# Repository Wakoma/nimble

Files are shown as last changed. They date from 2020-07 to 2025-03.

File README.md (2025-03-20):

<!--
SPDX-FileCopyrightText: 2020-2023 Eric Nitschke <eric@wakoma.co>
SPDX-FileCopyrightText: 2023 Robin Vobruba <hoijui.quaero@gmail.com>

SPDX-License-Identifier: CERN-OHL-S-2.0
-->

# nimble

[](
    https://spdx.org/licenses/CERN-OHL-S-2.0.html)
[](
    https://api.reuse.software/info/github.com/Wakoma/nimble)

<p align="center">nimble logo 256</p>

An open source, rapidly deployable, wireless mesh network. 

Anyone connected to the nimble can video and voice chat, stream videos, share files, build and run eLearning courses and website, create collaborative spreadsheets and documents, read e-books, play games, and so much more… completely offline. 

If a single internet connection is available, it can be plugged into the nimble to provide free or paid internet access to anyone on the network. The offline services and content are always available to users, regardless of internet availability.

Anyone in the world can build their own nimble with locally sourced hardware and 3D-printed components.

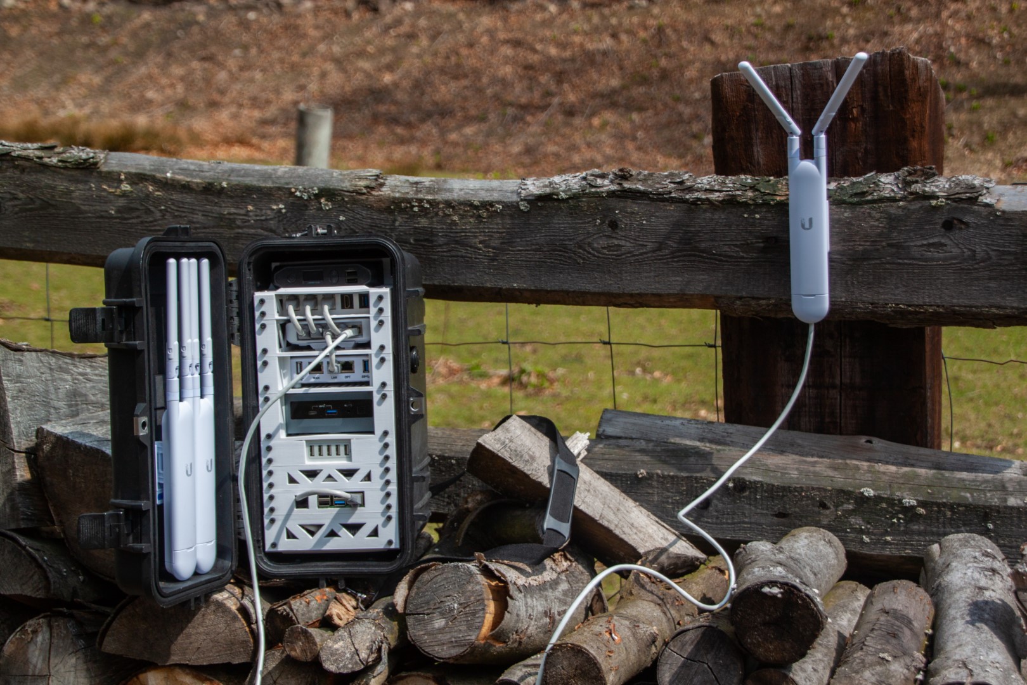
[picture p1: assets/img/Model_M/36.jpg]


## State of this repository

In 2024 we received a grant from NLnet Foundation to develop a smart documentation system which automatically generates all documentation and 3D models needed for any custom nimble configuration. 

<p align="center">6in NUC shelf</p>

See the announcement [here](https://nlnet.nl/project/HardwareManuals/).
Have a look at the other incredible projects they support [here](https://nlnet.nl/project/0).

A sneek preview of the nimble builder:

<p align="center">6in NUC shelf</p>

To create our interactive documentation generator we ended up creating an entirely new library called [CadOrchestrator](https://gitlab.com/gitbuilding/cadorchestrator).

## Useful Links

* [Nimble website](https://wakoma.co/nimble/)
* [Nimble printables page](https://www.printables.com/model/80708-wakoma-nimble-new-2021-model)
* [GitBuilding Repo](https://gitlab.com/gitbuilding/)
* Project Blogpost 1: [OTFN Hackathon](https://7bindustries.com/blog/otfn_hackathon.html).
* Project Blogpost 2: [Project Initiation](https://7bindustries.com/blog/nimble_project_1.html/

## Support

For more info have a look at <https://wakoma.co/nimble>,
or reach out to <mailto:info@wakoma.co>.

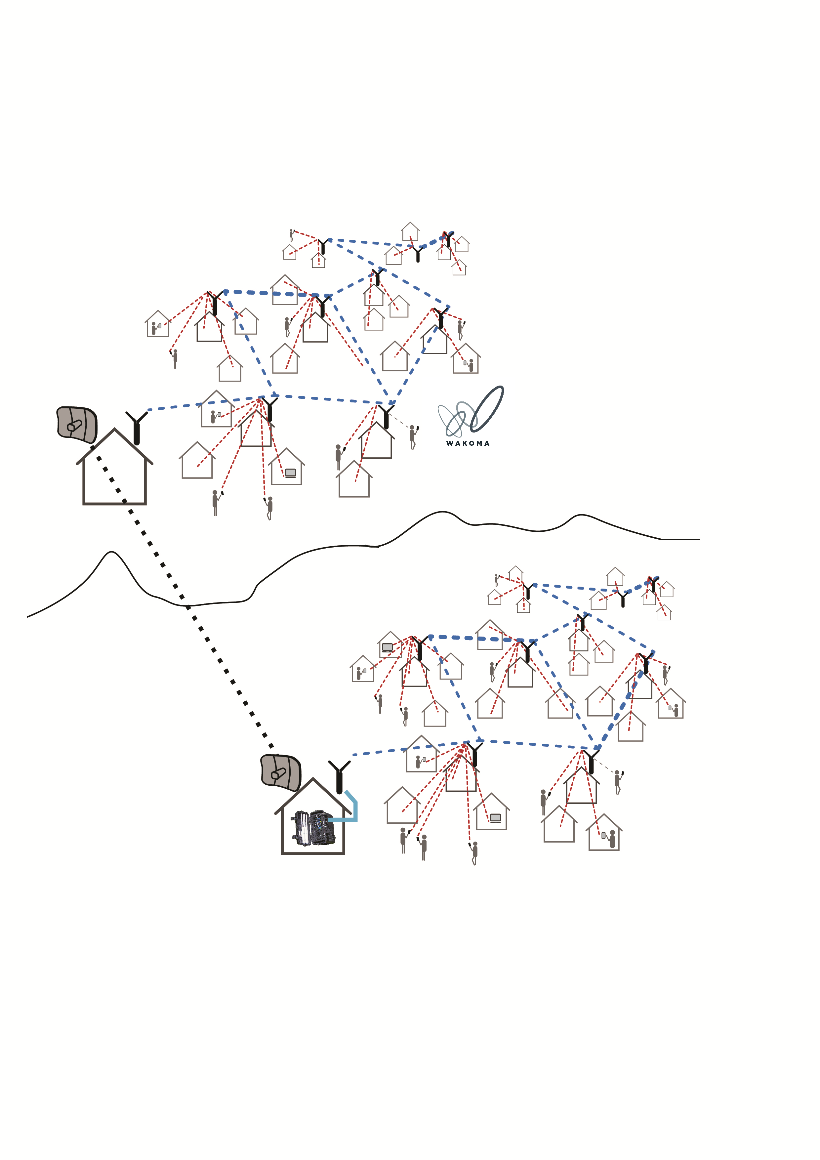
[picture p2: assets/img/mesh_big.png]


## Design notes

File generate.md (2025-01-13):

<!--
SPDX-FileCopyrightText: 2023 Andreas Kahler <mail@andreaskahler.com>

SPDX-License-Identifier: CERN-OHL-S-2.0
-->

# Automatic generation of configured Nimble hardware

## Overview

Nimble hardware models are generated using Python. For CAD we used [CadQuery](https://cadquery.readthedocs.io/en/latest/intro.html). CadQuery scripts can be found in the `mechanical` directory, with individual components in the `mechanical/components/cadquery` directory. Our CadQuery scripts also use the `nimble-builder` module of helper functions.

Our preferred way to generate the models needed for a nimble configuration is via our orchestration module `nimble-orchestration`. This uses an orchestration tool called [CadOrchestrator](https://gitlab.com/gitbuilding/cadorchestrator) This can be used to generate trays for networking components, nimble-rack components, and a final CAD assembly. The orchestration system uses [cq-cli](https://github.com/CadQuery/cq-cli) to execute CadQuery scripts, and [ExSource Tools](https://gitlab.com/gitbuilding/exsource-tools) to manage the process of turning scripts into useable models. The orchestration script will eventually use [GitBuilding](https://gitbuilding.io) to generate assembly manuals.

## Installation

You must have [Python 3.10](https://www.python.org/about/gettingstarted/) or higher installed on your system and also have pip installed. We recommend that you use a [Python virtual environment](https://realpython.com/python-virtual-environments-a-primer/) for interacting with nimble.

Clone or download this repository to your computer

Open a terminal (for example PowerShell in Windows) and navigate to this repository

Run:

    pip install -e .

*Note, if pip doesn't work depending on your system is configured you man need to replace `pip` with `pipx`, `pip3`, or `python -m pip`.*

## Running the code

### Lunching the configuration server

Starting in the root directory of this project. First you will need to generate the configuration options. To do this run:

    gen_nimble_conf_options

Next run:

    cadorchestrator serve

The server should now be available at http://127.0.0.1:8000/

### Generating a specific configuration from command line

The script `cadorchestrator generate` can be used generating a complete set of information for a nimble configuration from the command line.

Currently the configuration is just a list of the networking components which are hard coded. At a future date it should be possible to pass a configuration and other parameters to this script.

To generate run the following:

    cadorchestrator generate '{"device-ids": ["NUC10i5FNH", "Raspberry_Pi_4B", "Raspberry_Pi_4B"]}'

This should create the `build` directory. Inside this the `printed_components` directory should contain a number of `stl` files that can be 3D printed. It will also contain `step` files for each of these components.

The script also creates an `stl` and a `gltf` of the final assembled rack. **Don't print this, it is not going to print properly as a single piece!**

It also creates a number of files that are used by the orchestration script.

At a later date this script will be improved to create a directory (and associated zip-file of each configuration).

### Generate static

The script `generate-static.py` is used to create a number of example components for a Nimble rack. The script is not trying to support any specific configuration, but is instead being developed to provide a static library interface for which a large number of Nimble components can be downloaded.

To run this script, run the following command:

    python generate_static.py

This should create the `build` directory. Inside this the `printed_components` directory should contain a number of `stl` files that can be 3D printed.

The script also creates a simple web-page with an index of all of the files. The final link to the "Partially complete automatically generated documentation" will be broken unless you also run `generate.py` (see below).

It also creates a number of files that are used by the orchestration script.

If you don't want to run this locally you can see a [hosted version of the output](https://wakoma.github.io/nimble/).

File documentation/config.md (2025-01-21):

#  Your Nimble Configuration

The nimble is a modular rack-and-shelf system. The first part of construction is to 3D print the custom parts, and then to assemble the shelves.

The shelves in your system are:

{{listpages, tag:shelf}}

Once you have assembled each shelf, you will [construct the rack](construction.md){step}.

Make sure you have [all the parts you need]{bom}, before you start assembly.

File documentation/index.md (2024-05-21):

# Nimble Assembly Guide

## What is Nimble

Nimble is an open source, rapidly deployable, wireless mesh network.

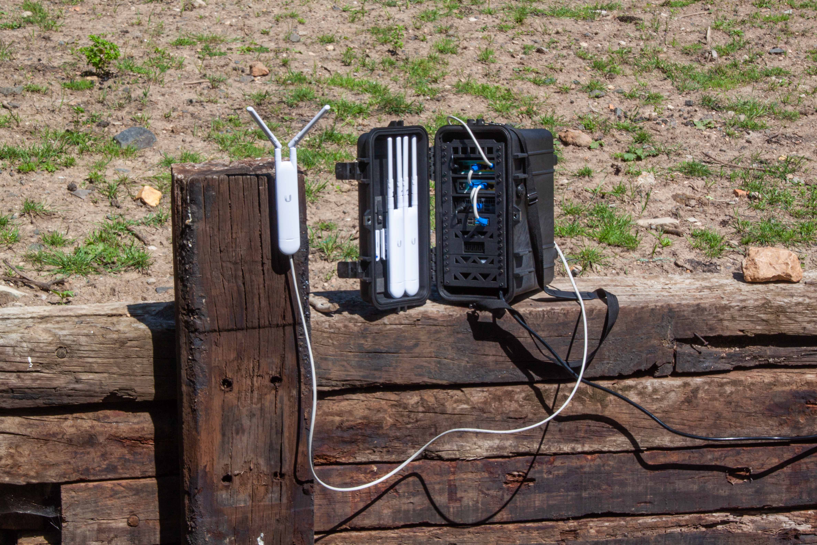
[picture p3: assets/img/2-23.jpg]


Anyone connected to the nimble can video and voice chat, stream videos, share files, build and run eLearning courses and websites, create collaborative spreadsheets and documents, read e-books, play games, and so much more… completely offline.

If a single internet connection is available, it can be plugged into the nimble to provide free or paid internet access to anyone on the network. The offline services and content are always available to users, regardless of internet availability.

Anyone in the world can build their own nimble with locally sourced hardware and 3D-printed components.

You can find out more about Nimble on [our website](https://wakoma.co/nimble/).

## Customisation

Nimble, as an open source project, is designed so that you can tailor it to your own needs and to the hardware that you have available.

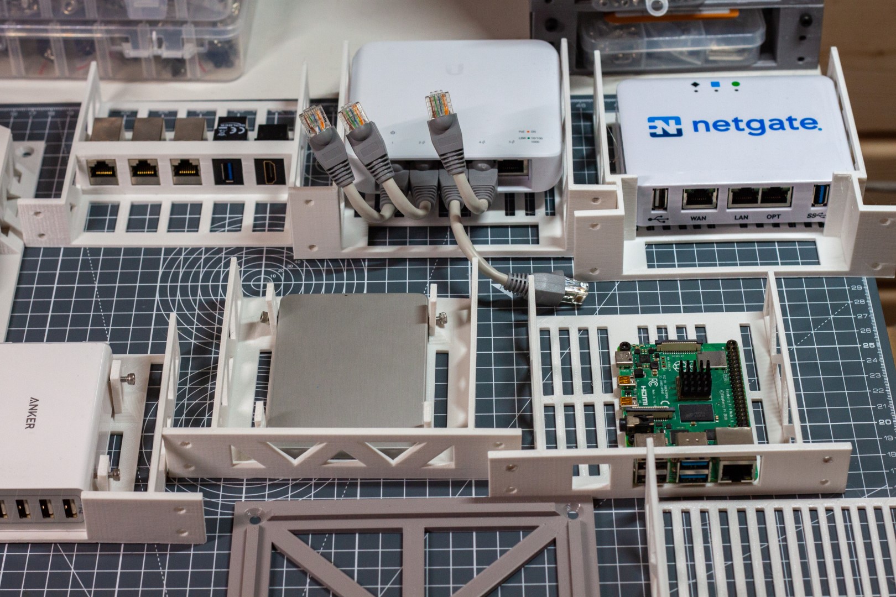
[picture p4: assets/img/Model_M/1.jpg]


We are [working on building an interface for customising your nimble](https://github.com/Wakoma/nimble/pull/23). In the mean time this is an example of the assembly instructions for a specific configuration.

To customise your Nimble you can go to [our GitHub](https://github.com/Wakoma/nimble). If you aren't sure where to start, you can always ask for help by [opening an issue](https://github.com/Wakoma/nimble/issues) or [starting a discussion](https://github.com/Wakoma/nimble/discussions).

## Building your Nimble

In the next pages we will build [your nimble](config.md){step}.

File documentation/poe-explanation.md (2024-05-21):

---
Tags: info
---

# Power over Ethernet (PoE)

Many of the devices in your Nimble are powered directly through the Ethernet cable.

Power over Ethernet allows both data and power to be transmitted between devices using only a single cable. This really cuts down on excess cables.

There is far more information on Power over Ethernet at [wikipedia](https://en.wikipedia.org/wiki/Power_over_Ethernet)

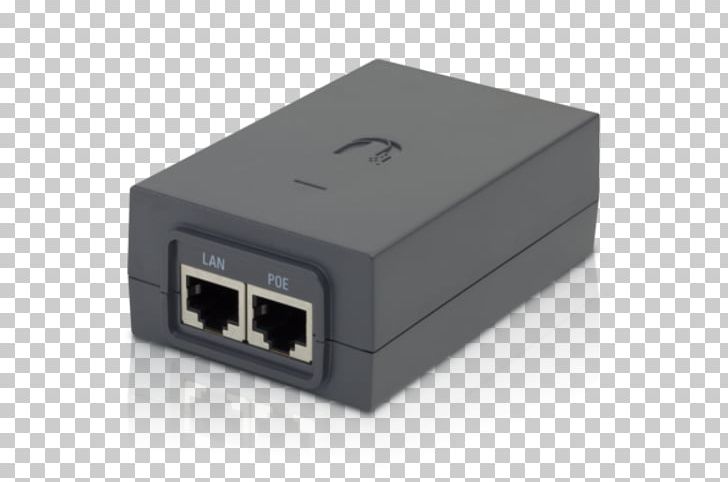
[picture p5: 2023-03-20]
assets/img/Network_Hardware/poe50.jpg

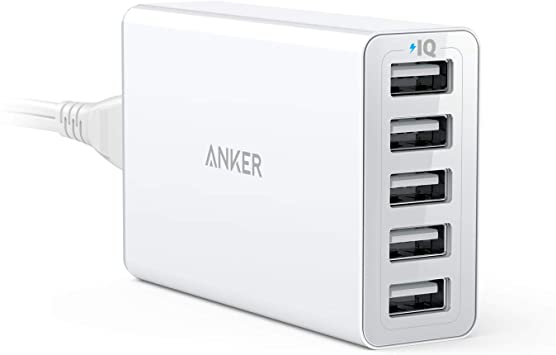
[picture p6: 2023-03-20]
assets/img/Network_Hardware/power2.jpg

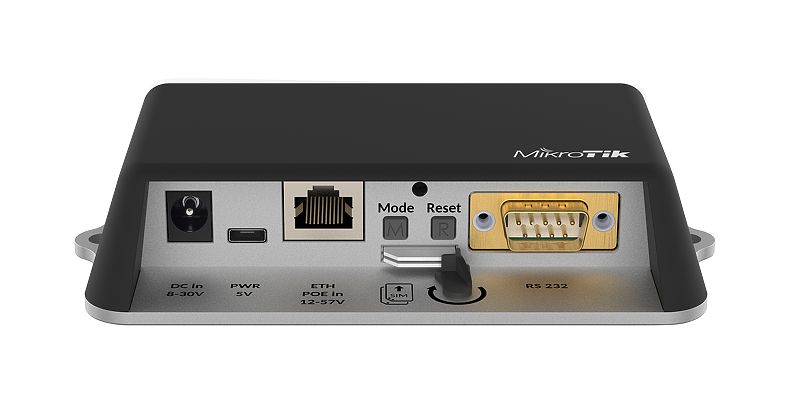
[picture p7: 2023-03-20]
assets/img/Network_Hardware/1604_l.jpg

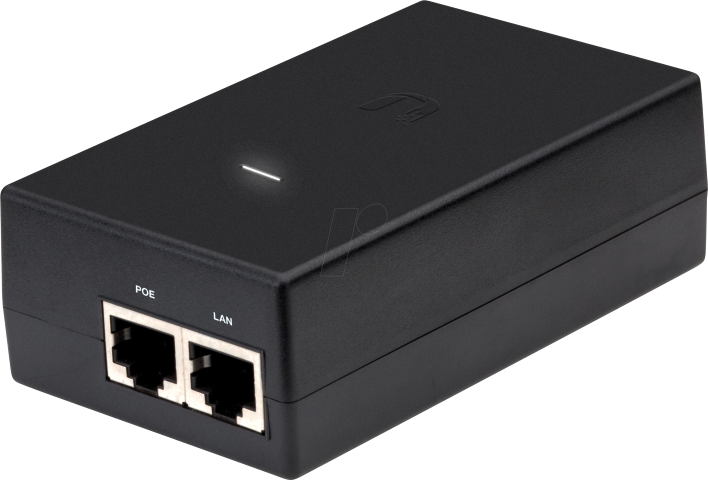
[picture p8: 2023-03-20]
assets/img/Network_Hardware/UBI_POE-50-60W_01_Small.png

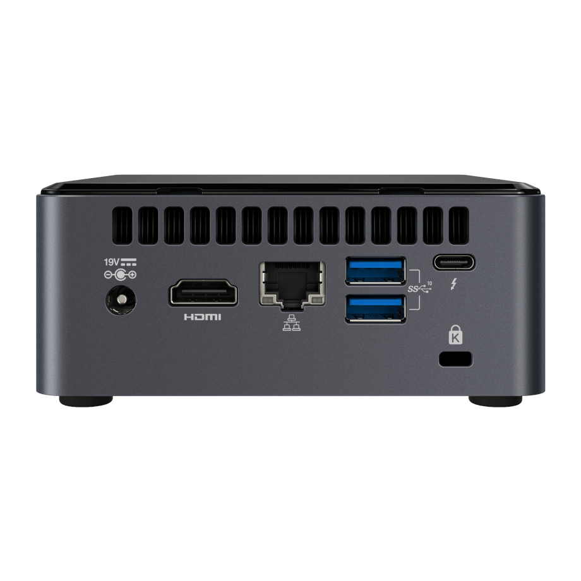
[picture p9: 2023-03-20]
assets/img/Network_Hardware/NUC10i5FNH.png

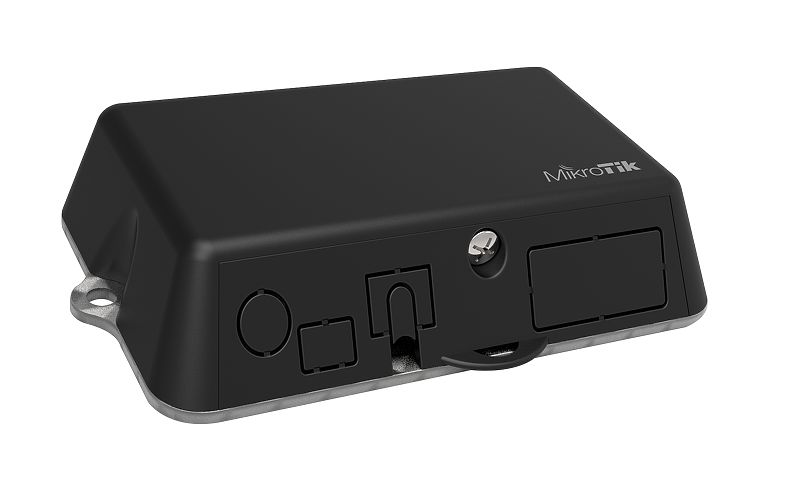
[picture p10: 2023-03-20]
assets/img/Network_Hardware/1513_l.jpg

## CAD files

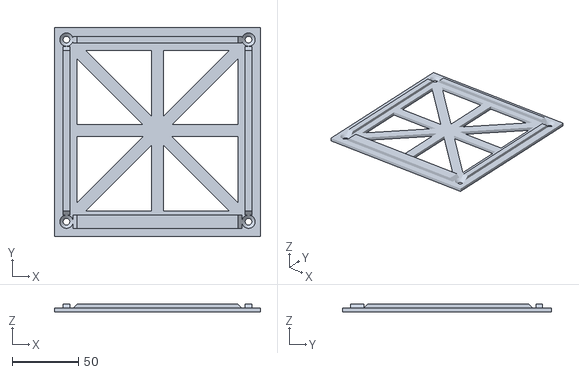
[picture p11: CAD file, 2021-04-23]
3D Designs/top-draft-v2.1-3mm.stl
155.0 x 157.0 x 6.00

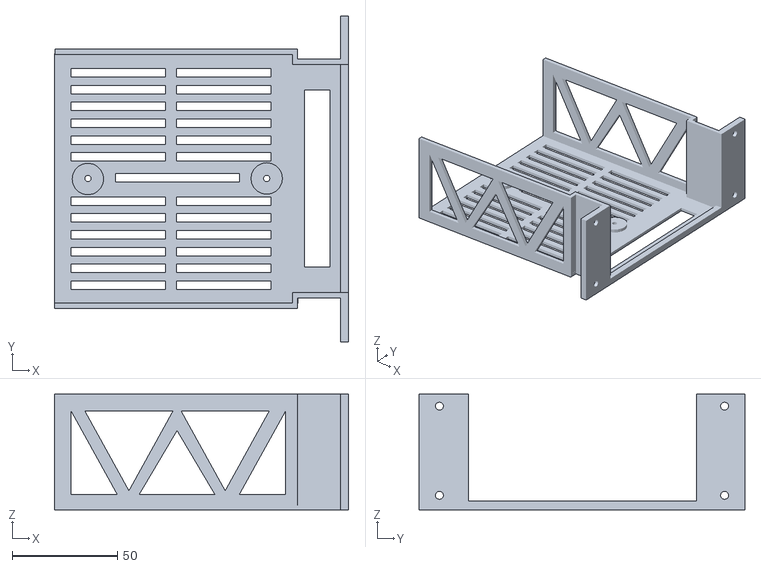
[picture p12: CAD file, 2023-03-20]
gen/mech/tall_nuc_shelf.stl
140.0 x 155.0 x 55.0

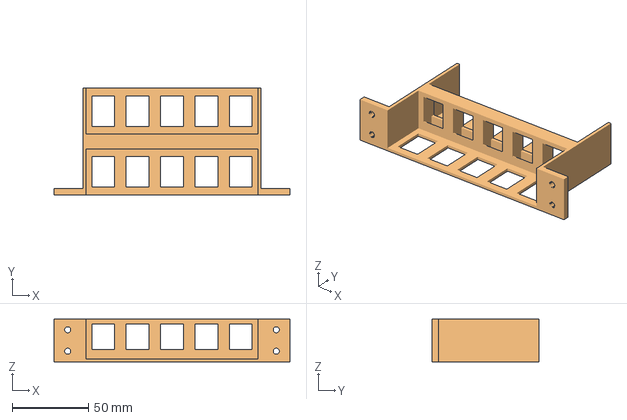
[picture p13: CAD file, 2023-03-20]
mechanical/components/FreeCAD/patch-panel.FCStd
155.0 x 70.0 x 28.0 mm
Fusion (Meshed)002

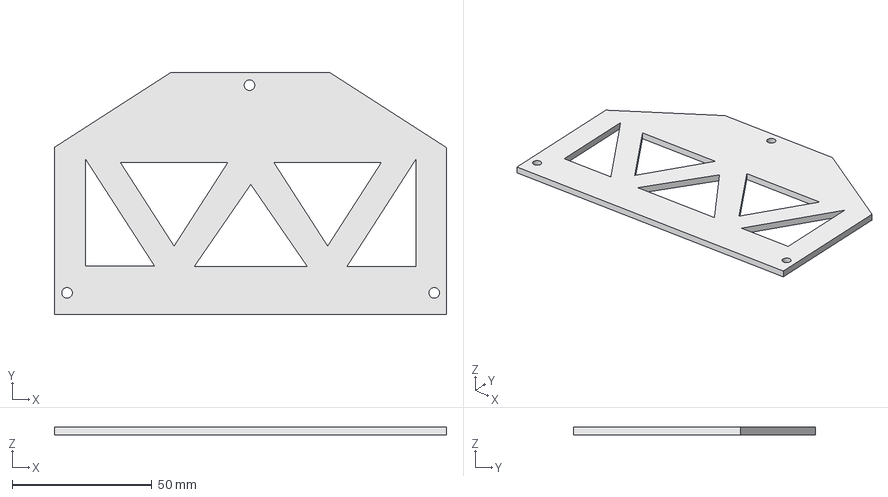
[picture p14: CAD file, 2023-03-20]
src/mech/freecad/omni_20_top.FCStd
140.5 x 86.9 x 2.80 mm

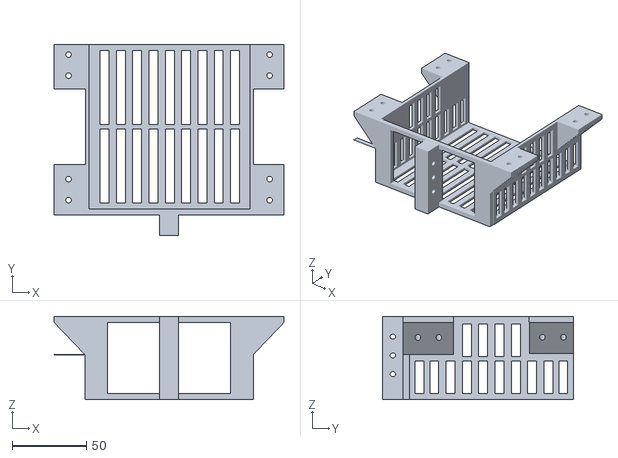
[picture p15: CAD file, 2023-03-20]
gen/mech/power_box.stl
155.1 x 129.0 x 56.0

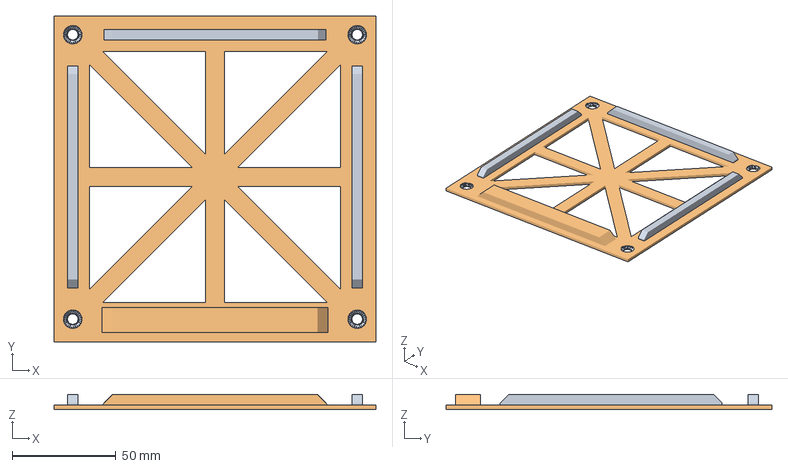
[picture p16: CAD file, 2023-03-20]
mechanical/components/FreeCAD/case-top-draft.FCStd
155.0 x 157.0 x 7.00 mm
Pocket001 (Meshed)004

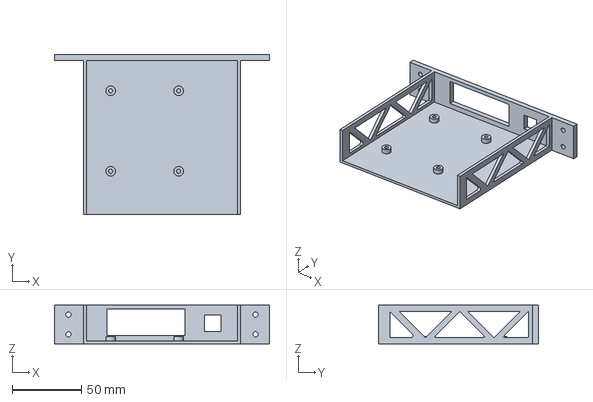
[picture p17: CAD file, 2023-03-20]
src/mech/freecad/rpi_4b_shelf.FCStd
155.0 x 115.0 x 28.0 mm

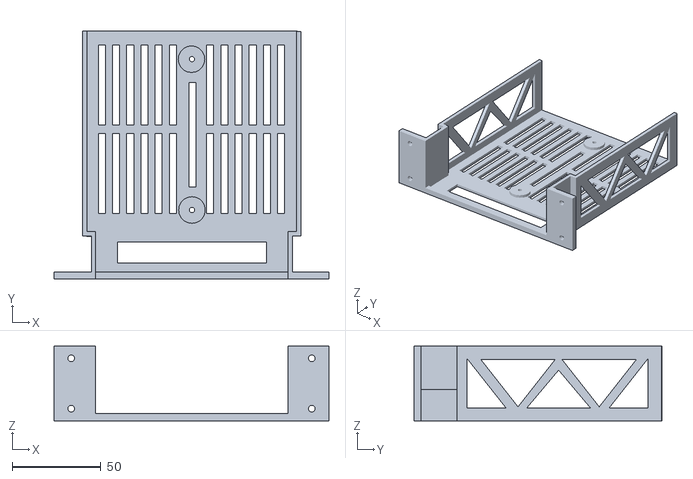
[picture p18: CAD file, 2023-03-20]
gen/mech/nuc_shelf2.stl
155.0 x 140.0 x 42.2

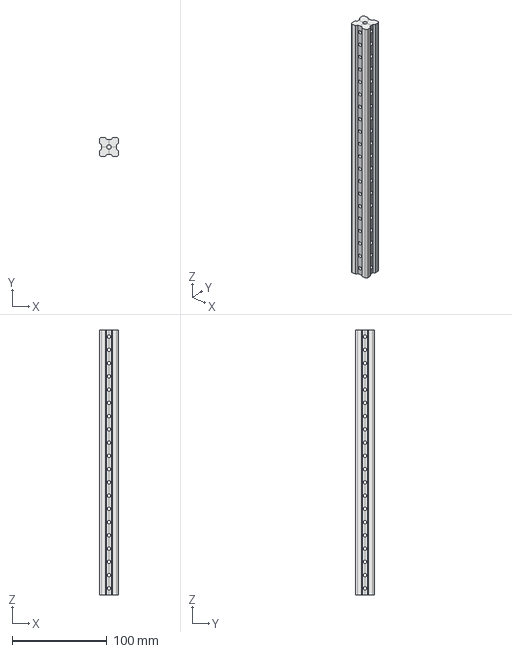
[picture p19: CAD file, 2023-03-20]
src/mech/freecad/master_rail.FCStd
20.0 x 20.0 x 280.0 mm

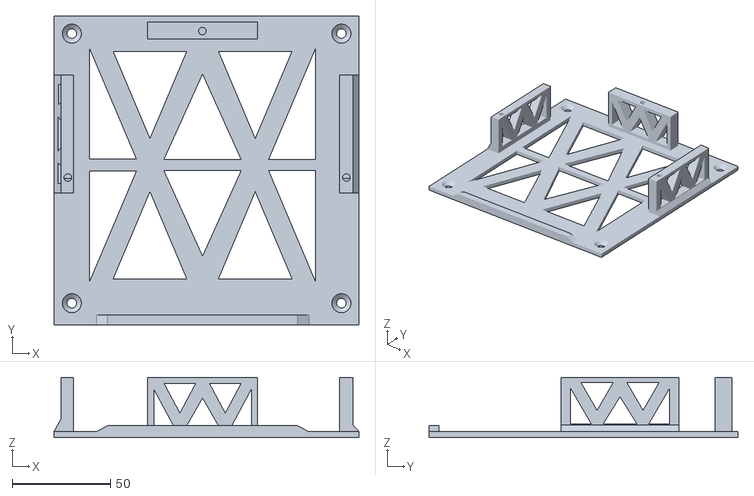
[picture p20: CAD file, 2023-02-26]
gen/mech/usg.stl
155.0 x 157.0 x 30.5

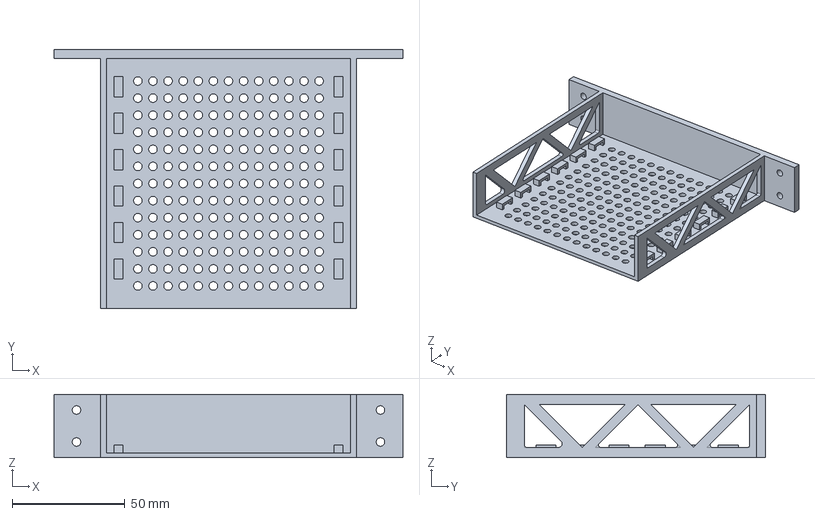
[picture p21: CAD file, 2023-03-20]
src/mech/freecad/base_shelf.FCStd
155.0 x 115.0 x 28.0 mm

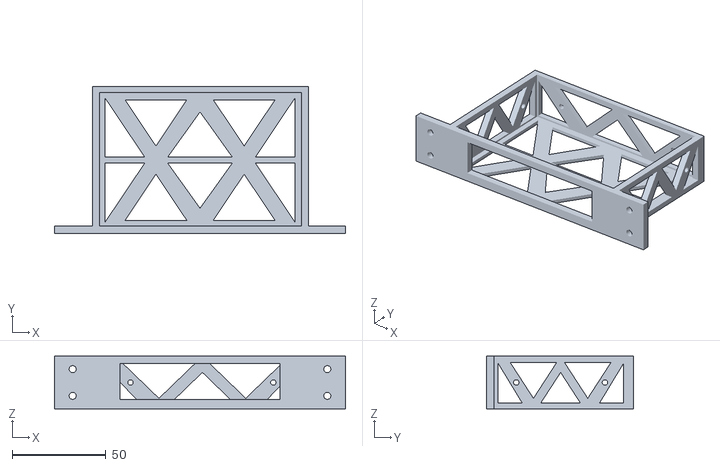
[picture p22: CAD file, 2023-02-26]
gen/mech/flex_mini_shelf.stl
155.0 x 78.1 x 28.0

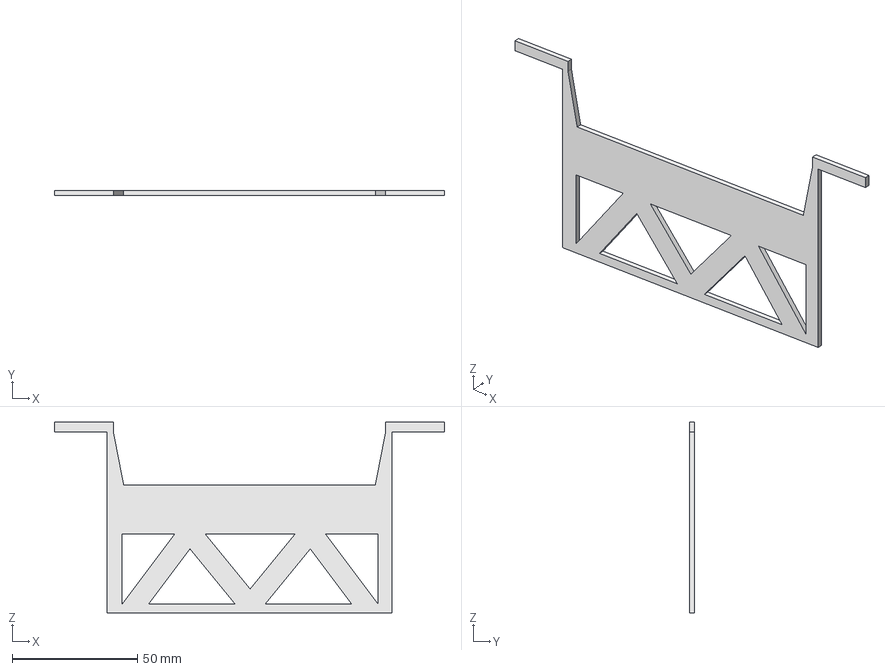
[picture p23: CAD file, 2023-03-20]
src/mech/freecad/triangle_master.FCStd
155.5 x 2.00 x 76.0 mm

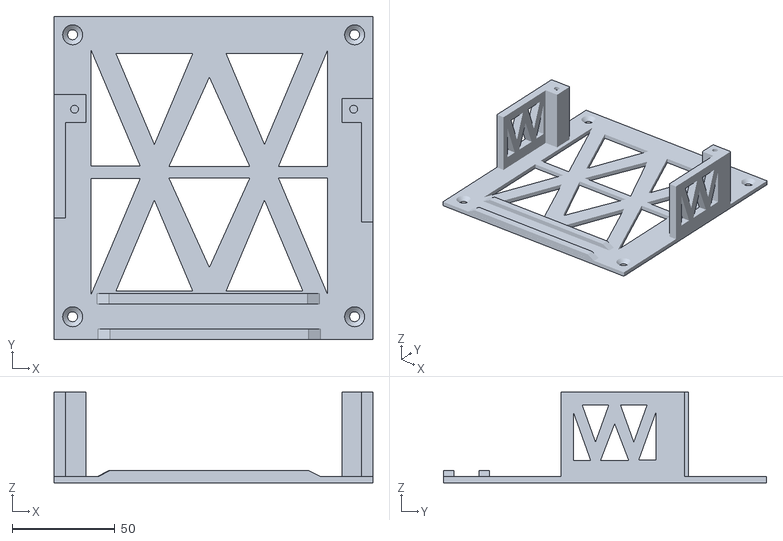
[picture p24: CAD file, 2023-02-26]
gen/mech/scarlett_solo.stl
155.0 x 157.0 x 44.0

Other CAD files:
gen/mech/ltap_mini_shallow.stl
gen/mech/keystone_patch_panel_2_units_short.stl
gen/mech/usg_top.stl
gen/mech/ap_mount_for_1430_top.stl
gen/mech/3.5_hdd_shelf.stl
gen/mech/ap_mount_for_1430.stl
gen/mech/ap_mount_for_1430_bottom.stl
gen/mech/dual_ssd_shelf.stl
gen/mech/generic_shelf.stl
gen/mech/keystone_patch_panel_2_units.stl
gen/mech/mikrotik_shelf.stl
gen/mech/nuc_shelf.stl
gen/mech/nuc_shelf_tall.stl
gen/mech/omni_20.stl
gen/mech/omni_20_top.stl
gen/mech/patch_panel_2_units.stl
gen/mech/power_cage.stl
gen/mech/rack_leg_21_units.stl
gen/mech/rpi_4b_shelf.stl
gen/mech/sg-1100_shelf.stl
gen/mech/stuff_shelf_thin.stl
gen/mech/top.stl
gen/mech/usb_hub_shelf.stl
gen/mech/usw-flex_shelf.stl
mechanical/Legacy/STLs/3.5_hdd_shelf.stl
mechanical/Legacy/STLs/ap_mount_for_1430.stl
mechanical/Legacy/STLs/ap_mount_for_1430_bottom.stl
mechanical/Legacy/STLs/ap_mount_for_1430_top.stl
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

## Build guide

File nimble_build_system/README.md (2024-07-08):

The nimble build system is a python module containing custom functionality for building the nimble hardware.

This is divided into three sub-packages:

* `cad` - This contains any helper functions for building the Nimble CAD models. This does not contain the scripts for generating specific CAD models and assemblies. These are held in the `mechanical` directory of the repository.
* `orchestration` - This contains code for the Nimble project's interaction with [CadOrchestrator](https://gitlab.com/gitbuilding/cadorchestrator)
* `utils` - This contains assorted utility scripts, for example for updating the JSON configuration files.

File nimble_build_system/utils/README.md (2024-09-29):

The utilities sub-module of the nimble build system contains scripts that are needed for project specific tasks such as updating config files

## nimble_devices_updater.py

This converts the CSV that is downloaded from NocoDB into something that can be used by the orchestration/generation scripts. The scripts use the `devices.json` file that is in the root of this repository. This should eventually be replaced by a direct connection via the NocoDB API. This utility requires that it be passed the path to the CSV file to convert.

**Usage:**

```bash
./nimble_devices_updater.py
```

The `devices.json` file it creates is committed to the repository.

## gen_nimble_conf_options.py

This script used `devices.json` to create the configuration used by CadOrchestrator to set the configuration options that the user can select when generating a nimble.

Assuming that the `nimble_build_system` is installed using setup.py, this script is as an entry point and should be on your PATH.

Starting in the root directory of this project, run:

```bash
gen_nimble_conf_options
```

This will generate the configuration options in the file `OrchestratorConfigOptions.json`. This file is ignored by Git.

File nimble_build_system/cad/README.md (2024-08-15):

This directory holds CAD files that are used to generate Nimble racks.

# Dimension Names

Standard dimension names are needed to ensure proper orientation of the shelf, hardware and rack models, and the diagram below outlines the system employed for the Nimble rack and shelf CAD. When creating new CAD models, or adding data for existing hardware to the database, please follow these conventions.

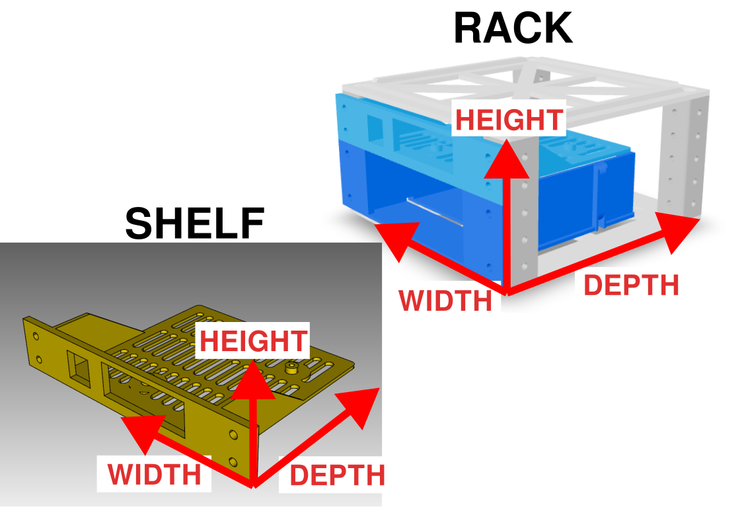
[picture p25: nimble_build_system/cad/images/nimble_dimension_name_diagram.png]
Nimble Dimension Naming Diagram


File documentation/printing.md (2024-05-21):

# 3D Printing

{{BOM}}

[PLA]:parts/filament.md "{cat:consumable}"

## Print the custom components {pagestep}

Using the slicer that comes with your [3d printer](parts/3dprinter.md){qty:1, cat: tool}, slice the following parts, and then print them.

Some parts require support. A brim is advised for all parts.

| Qty | Item | Material | File | Supports<br>Required?|
|-----|---|---|---|---|
{{foreachmakeitem: "| {{qty}} | {{id}} | {{weight-qty}} of [{{material}}]{qty:{{weight-qty}}}  | [{{stlname}}]({{stl-file}}){previewpage}|{{supports, default: No}}|"}}

You can [download all of the STLs as a single zipfile](all-stls.zip){zip, pattern:"*.stl"}

## Remove the brim {pagestep}

Remove the brim with a [utility knife](parts/utility_knife.md){qty:1, cat:tool}

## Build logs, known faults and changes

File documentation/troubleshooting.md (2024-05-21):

# Troubleshooting and Support

**Write me!!**

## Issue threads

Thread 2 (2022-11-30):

Open Source Hardware - some Info is missing

timmwille, 2022-11-30:
Hi Guys do you need some suggestions regarding the Openess of this project? CERN OHL 2.0 (S or W might fit best) or other License might be best, currently I could not find a License file/note.

Where would I find the Source files (so far the stl is mesh not CAD based format)?

I'm working within the context of Open Source Ecology and the Open Culture agency within South Sudan, Uganda and other regions, might be very interesting to collaborate.

timmwille, 2022-11-30:
from the software side all seems clear: https://github.com/Wakoma/Lokal

thanks for the great work, I would love to test it

timmwille, 2022-12-01:
I hope my PR helps to make it easy, in general the source files can be in the tinkercad though on my end even activating al skripts it looks like this:

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

ericnitschke, 2022-12-02:
thanks very much @timmwille and @moedn.  Would love to jump on a call with your team to discuss license options, Lokal install, etc. On our main website we do have the nimble license as CC-BY-SA 4.0, but we're open to other options.

Looks like one must be logged into Tinkercad to access the source files, which isn't ideal.  Glad to move/convert/share them as necessary.

New Lokal release coming out very soon, along with some much needed documentation.

Looking forward to connecting soon.

moedn, 2022-12-02:
Cool! I'm pretty flexible next week. @ericnitschke please feel free to pick a slot that suits you :) Not sure if @timmwille will be able to join since he's quite busy these days, but I'll be happy to bring in his input :)

hoijui, 2023-03-21:
All of this has been solved in the hackathon on march 3. and 4. 2023. The project is now primarily using `CERN-OHL-S-2.0`. :-)

(Issue can be closed)

ericnitschke, 2023-03-21:
Thank you everyone for your inputs on this at the hackathon!  Case closed.

Closed 2023-03-21.

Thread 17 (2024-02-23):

Ziptie Shelf Prototype

ericnitschke, 2024-02-23:
New design for attaching any* hardware to a shelf.

STL Link: https://github.com/Wakoma/nimble/blob/master/gen/2024%20designs/parametric%20(primary)/shelf_6in_2u_anker-atom3slim.stl

ericnitschke, 2024-02-23:
design by @drayde
test print:

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

drayde, 2024-06-10:
@ericnitschke can we mark this as done?

David-ksturnpike, 2024-06-10:
could this be merged into issue number #24?  or would this be a separate issue?

drayde, 2024-06-10:
If support of velcro is the only issue, i'd close this one. If there are other issues to be addressed, I'd handle those here

julianstirling, 2024-06-10:
I agree. I think we close this a zip-ties are already working and implemented. We can keep #24 open as this reminds us that we should also support Velcro as and when we have time.

Closed 2024-06-10.

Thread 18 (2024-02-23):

M6 Screw Prototype Shelf & Legs

ericnitschke, 2024-02-23:
New designs for M6 screws by @drayde

Pros: M6 will fit standard (EU) server racks.
Cons: M6 screw holes on 6in shelves looks odd
Idea: build screw hole customizer.

ericnitschke, 2024-02-23:
STL File: https://github.com/Wakoma/nimble/blob/master/gen/2024%20designs/parametric%20(primary)/M6_raspi.stl

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

julianstirling, 2024-02-23:
What screw sizes are normally used? If you want to make it somewhat US and UK friendly then the holes can be set from 1/2-20 clearance which is also a slightly loose M6 clearance which is fine for rack mounting.

ericnitschke, 2024-02-23:
We originally started using M4 because....reasons.  We've used M4 for shelves, and M5 for "top/hat" shelves that sit on top of the rack.

Standard sizes seem to be "the English 10-32 and 12-24 and the metric M5 and M6". https://www.networkcomputing.com/data-centers/cage-nuts-ultimate-guide/page/0/1

"M5 and M6 are metric rack screws, and you use the bigger screws to hold a heavier load in a server. 10-32 and 12-24 are non metric and tell you how wide the screw plug is and how many complete threads it has from the head of the bolt to the tip. "  https://www.reddit.com/r/sysadmin/comments/5jesd7/stupid_question_about_rack_screws/

All of the racks and shelves shipped here within the EU have come with M6.

With the new parametric designs it seems that we *could offer a choice between the 4 in the builder/customizer.  Otherwise because "10-32 and M5 are close enough that you might be able to force an M5 bolt into a 10-32 nut", perhaps we should switch to M5 as the default size?

julianstirling, 2024-02-23:
I have normally used M5 on rack systems. I think M5 seems like a sensible standard. If we make the clearances correct for M5 and 10-32, then it can be configurable which physical nuts and bolts you use. I think sticking and m5 bolt into a #10-32 nut isn't great. But if we say get either M5 nuts and bolts or #10-32s. Just don't mix and match?

***Side rant***
Americans use the therm "English" for ANSI screws that are not the same as the old Imperial screws used in England. You just want to blame your terrible screws on us!

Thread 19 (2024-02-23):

Decide on Shelf/Component Filename Format

ericnitschke, 2024-02-23:
Ideas:

hardware item_rack size (6 or 10)_number of units/holes_version

thoughts @julianstirling?

julianstirling, 2024-02-23:
Sorry, I am a bit confused without more context, so I can't really comment.

ericnitschke, 2024-02-23:
We currently have dozens of shelves/models.  With the new tools we'll likely have hundreds quite soon. Was looking at g-code output options (https://help.prusa3d.com/article/list-of-placeholders_205643) and thought it could be useful to standardize model filenames for documentation/BOM/GitBuilding/etc.

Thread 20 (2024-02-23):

STLs in main Repository

julianstirling, 2024-02-23:
I have just notices we are committing the STLs to the repo. STL files can get large and as Git clone pulls the entire history this very quickly turns into a project that can only be contributed to by people with good internet connection. Something we cannot ensure Nimbe contributors will have. OpenFlexure had this issue, it made it almost impossible to work on the repository in Africa.

Is the idea to commit all the legacy nimble files as STLs then remove them as we make parametric ones? Or are these the new generated ones? f they are they have no business being in a repo and should be purged from the history with BFG and we should be using CI to generate them

Can we have a meeting to discus the repo?

ericnitschke, 2024-02-23:
Thanks, @julianstirling. Solid point.  I just put them (old ones and new) up [here](https://github.com/Wakoma/nimble/tree/master/gen) for the sake of openness.

We could perhaps keep the archive and parametric files under development in Nextcloud, and just add the most recent versions on GH? (or offload to Printables or Appropedia?) Glad to discuss on the next call.

It might also make sense to build a compressed offline-first archive of all designs and documentation in a few months. (i.e. https://github.com/openzim/zim-requests/issues/793).

ericnitschke, 2024-02-27:
consensus that STLs should be removed from repo and added to static site for now

drayde, 2024-02-27:
removed the new STL files, left in the 2023 versions in for now (to be deleted when we have the new workflow ready).
For new static site, see #21

Closed 2024-02-27.

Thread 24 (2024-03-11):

zip ties VS Velcro on the new shelf creation

David-ksturnpike, 2024-03-11:
suggestion for the shelves, could we use Velcro in addition or in place of zip ties? I suggest this as if you use zip ties and want to change the device on the shelf then you would have to cut the zip tie in order to change the device out. however, if Velcro was used then all you would have to do would be to undo the Velcro and then change the device out and then re Velcro the device to the shelf. granted this would all be dependent of local use of the system and how "rough" the environment is.

drayde, 2024-03-21:
It seems many of these velcro cable ties are 12mm wide. I'll make the channel wider to fit these and then you could use both zip ties and cable ties

drayde, 2024-03-21:
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
This is what it would look like. It is a bit harder to print without support, but I guess it still will work.
@ericnitschke do you want to give it a try? What device? What to try a new one where we do not yet have a shelf?

julianstirling, 2024-03-21:
12mm bridges should be fine

This is a 60mm bridge that normally prints fine
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
The same part has a 75mm bridge as well, but I'd have to dismantle it a bit more to show you. This is pushing the limit of a standard printer, but 12mm should be no problem

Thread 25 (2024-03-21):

Avoid tapping plastic with machine screws where possible

julianstirling, 2024-03-21:
We found in OpenFlexure that most of out failures in the field that required re-printing were due to tapping plastic holes with machine screws. The following solutions worked well for us:

* Use Nut traps where possible.
* For small circuits boards like the raspberry Pi, use 2.2mm self tapping screws
* Use triangular holes for tapping into as they are more forgiving if the hole it printed too small.

hkienle, 2024-10-27:
Interesting points. Is there a reference for the triangular holes?

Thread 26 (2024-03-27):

Leg rotation not constrained

julianstirling, 2024-03-27:
In the current design of the legs, they are free to take any rotation.

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

I think adding extra screws would be bad but it might be worth adding a raised rim on two sides of the leg on the bottom to constrain the legs rotation

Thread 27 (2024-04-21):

PNG, SVG or Both in Documentation?

jmwright, 2024-04-21:
During the hackathon we were limited to SVG output (outlines and hidden lines only). After seeing the renders on the field dissection microscope (a variant of the OpenFlexure microscope) on [Experiment.com](https://experiment.com/u/byLz1g), I developed a [Gist](https://gist.github.com/jmwright/e9ce05b197ea64d54bab7ca4ee4469ee) that provides a method of outputting similar PNG renders from CadQuery.

I have two questions:

1. Do we want to incorporate PNG export in the auto-documentation?
2. If so, how do we want to incorporate it?

We could use a mix of SVG and PNG depending on the situation (SVG for views where hidden lines need to be seen, or with exploded views listing the parts). We could also just decide to use one or the other.

The Gist I provided above is not complete (no camera or image size control), but I can push it forward and work on getting it integrated into CadQuery if there is interest.

julianstirling, 2024-04-21:
While I think that SVG should be universal, I have seen more website viewing issues with SVG, so I think PNG is great.

I don't understand the technicalities enough about the hidden lines. Is there a reason the means that hidden lines will be seen differently if we choose PNG over SVG? If so, do you have and example of the differences?

jmwright, 2024-04-21:
@julianstirling  I'm using the VTK library that OpenCASCADE is usually paired with to export the PNG images, and I haven't seen anything that would allow hidden lines to be included in those renders. So the rendering of the PNG will only show the outside faces of the object (at least for now), whereas with SVG export I can request to see hidden interior lines. However, the SVG export won't show shaded faces the way the PNG images will, so there are pros and cons to each type of export.

Hidden line example in SVG: https://codeberg.org/7BIndustries/poc-stereoscope/raw/branch/main/docs/images/stereoscope_center_piece_with_screws_in_assembly_exploded_annotated_side_view.svg

The PNG exports will look similar to your dissection microscope images I linked above.

jmwright, 2024-04-22:
I generated a few sample images in both PNG and SVG format to help illustrate the differences. I got the views as close as I could, but the camera settings between the PNG and SVG renderers are not 1-to-1. The renders are of a simple assembly with two cubes in it, and the camera is set to Y-up in the exports because that is the default with SVG. The [PNG export Gist](https://gist.github.com/jmwright/e9ce05b197ea64d54bab7ca4ee4469ee) has been updated with both camera and image size control (as well as a parallel projection toggle).

## SVG with Hidden Lines
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

## SVG without Hidden Lines
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

## PNG
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

## Screenshot of Assembly from CQ-editor for Reference
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

drayde, 2024-04-22:
I vote for having both options :-)

jmwright, 2024-05-01:
I think this question has been answered, and the work is being tracked in #34 . Closing.

Closed 2024-05-01.

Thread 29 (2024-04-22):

Add GitBuilding Syntax for for top-down modular hardware

julianstirling, 2024-04-22:
This issue describes a task that forms part of the [Nimble smart doc project](https://github.com/orgs/Wakoma/projects/7) funded by the NLNet foundation. This work will enable work within this project but will happen in the [GitBuilding repository](https://gitlab.com/gitbuilding/gitbuilding)

julianstirling, 2024-04-22:
This has been identified as a shortcoming of GitBuilding for over 2 years
    https://gitlab.com/gitbuilding/gitbuilding/-/issues/227

The core implementation of the top down syntax was in this Merge request
    https://gitlab.com/gitbuilding/gitbuilding/-/merge_requests/187

For the 3D printing page it was necessary that the contents of the page itself had to be updated depending on which parts were printed. This is a generic problem for any type of documentation that has a number of pieces being made by a manufacturing process. It could be CNC machining or 3D printing, or a something a simple as a cutting list for timber. As discussed in the comments of the issue thread linked above. It was decided to add the data of the components that need to be manufactured to the YAML header of the page that is using them. A template for the manufacturing process can then be written to create the page that the reader will see. This was implemented in the following merge request:
    https://gitlab.com/gitbuilding/gitbuilding/-/merge_requests/195

Also merge requests https://gitlab.com/gitbuilding/gitbuilding/-/merge_requests/194 and https://gitlab.com/gitbuilding/gitbuilding/-/merge_requests/196, were bug fixes related to the implementation of this syntax.

This new syntax has then been tested using the exampled documentation repository for the nimble project
    https://github.com/Wakoma/nimble-example-documentation/pull/1

Closed 2024-04-22.

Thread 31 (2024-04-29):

Create initial set of scripted CAD shelves and frame

julianstirling, 2024-04-29:

julianstirling, 2024-06-10:
This was  done in #23, which was a combination of many smaller PRs. Work since has refactored this.

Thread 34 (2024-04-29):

Add annotation and png Export functionalitt to CAD Query

julianstirling, 2024-04-29:
This issue related to an external project (CAD query) but is necessary for the Nimble Smart Docs

jmwright, 2024-04-29:
PNG functionality is on a CadQuery branch [here](https://github.com/CadQuery/cadquery/tree/png). I will report back when I create a pull request for it. I would like to leave the PR in draft until we have shown that it meets our needs, and then I'll take it out of draft and work with the other core CadQuery devs to get it merged. This way we have two adjacent communities engaged in making sure the export functionality meets a wider range of needs.

jmwright, 2024-05-01:
I created a library last year which already has a couple of the features that we've talked about needing for this project. It's called [cq-annotate](https://github.com/jmwright/cq-annotate/blob/main/README.md). My thought is that I can just expand that library for this project, but I wanted to post it for discussion.

julianstirling, 2024-06-10:
Pushing the end date of this item back as the annotation feature is still evolving as we start to create the renders.

See also the discussion on annotated assembly screenshots: #61

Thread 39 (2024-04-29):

Create scripts to render outline of hardware for assembly images

julianstirling, 2024-04-29:
For core hardware this can be a quick CAD model of the device. For less common hardware we can create an approximate rendering from the dimensions and if available the front and back ports.

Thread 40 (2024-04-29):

Add needed assembly and render infromation to database

julianstirling, 2024-04-29:
For example which type of shelf should be used.

jmwright, 2024-10-21:
@ericnitschke Can the following information for the [Western Digital Red 3.5" HDD](https://www.amazon.de/-/en/Western-Digital-Internal-Hard-Drive/dp/B083XVY99B/ref=sr_1_5?th=1) be added to the database? There will probably be another entry like this coming later for SSDs.

```json
{
  "ID": "Western_Digital_Red_HDD",
  "Type": "Storage",
  "Hardware": "Western Digital Red HDD",
  "Brand": "Western Digital",
  "Model": "WD20EFAX",
  "Shelf": "HDD 3.5 Shelf",
  "Rack": "6 in",
  "ShelfId": "hdd35-6",
  "HeightUnits": "2",
  "LengthMm": "147.07 mm",
  "Depth": "101.60 mm",
  "Height": "26.16 mm",
  "PoEIn": "",
  "PoEOut": "",
  "WattageMax": "",
  "EstCostUsd": "$131.00",
  "ProductWebsiteUsd": "",
  "ProductWebsiteEur": "https://www.amazon.de/-/en/Western-Digital-Internal-Hard-Drive/dp/B083XVY99B/ref=sr_1_5",
  "RAM": "",
  "Field19": "",
  "PoEInInputVoltage": "",
  "Voltage": "",
  "Amperage": "",
  "WRTVersion": "",
  "OpenWRTLink": "",
  "Comments": "Part number is for the 2TB version"
}
```

ericnitschke, 2024-10-21:
Definitely. Wondering if we should add a "Storage" field, but it's probably overkill for now.

jmwright, 2024-10-21:
@ericnitschke Here is the entry for the WD Blue SSD drive.
```json
{
  "ID": "Western_Digital_Blue_SSD",
  "Type": "Storage",
  "Hardware": "Western Digital Blue SSD",
  "Brand": "Western Digital",
  "Model": "WDS100T3B0A",
  "Shelf": "SSD 2.5 Shelf",
  "Rack": "6 in",
  "ShelfId": "dual-ssd-6",
  "HeightUnits": "2",
  "LengthMm": "100.30 mm",
  "Depth": "69.90 mm",
  "Height": "7.10 mm",
  "PoEIn": "",
  "PoEOut": "",
  "WattageMax": "",
  "EstCostUsd": "$74.49",
  "ProductWebsiteUsd": "",
  "ProductWebsiteEur": "https://www.amazon.de/-/en/Upgrade-Dropbox-Professional-Western-Dashboard/dp/B09ZYQ84CM/ref=sr_1_4",
  "RAM": "",
  "Field19": "",
  "PoEInInputVoltage": "",
  "Voltage": "",
  "Amperage": "",
  "WRTVersion": "",
  "OpenWRTLink": "",
  "Comments": "Part number is for the 1TB version"
}
```

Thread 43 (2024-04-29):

Create mock-up of final UI

julianstirling, 2024-04-29:

jmwright, 2024-04-29:
As a companion to the server backend in #45 I created a simple web front end for testing.

[README](https://github.com/Wakoma/nimble/blob/smart_doc/doc_generator/server/README.md)

[HTML](https://github.com/Wakoma/nimble/blob/smart_doc/doc_generator/server/test_page.html)

[Javascript](https://github.com/Wakoma/nimble/blob/smart_doc/doc_generator/server/static/js/index.js#L6)

ericnitschke, 2024-06-22:
A few older mock-ups by Wakoma team. (front) end product will likely be quite different.

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

julianstirling, 2024-07-08:
These are nice. We also have the demo server which was in plain JS.

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

---

I think the best path forward is to move the current demo server into a more extensible framework (VueJS 3) and then have a bit of a think about it want to pull elements of this @ericnitschke mockups into the the server.

The issue I see with doing this is we are going to need the images and description text to be added to the database for each item. This isn't insurmountable, but may be a fair amount of work.

Closed 2024-07-08.

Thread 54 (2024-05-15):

Decide on configuration (and hash) structure

julianstirling, 2024-05-15:
To uniquely identify each Nimble Configuration we need to have some sort of unique "hash" for that configuration.

We first need to understand exactly what the possible configurations are. The way we currently pass the components into the orchestration is a list of the devices in the order they go into the rack.

I think we will also want a way to add rack options. Options like the screw sizes, or the total rack height to match the peli-case/container being used (we can pad out the excess with stuff shelves, or blanking plates).

I think our inputs are then:

```json
{
    devices: [device_id1, device_id2, ....],
    parameters:{
        parameter1: value,
        parameter2: value
    }
}
```

Are there other things we will need?

## Hashing strategy

We can just add these as a string (with parameters sorted as @jmwright has in example code) or we can pass them into a hashing function. My gut feeling is to lass it into a hashing function to keep the names shorter, but it may also obscure them.

## Implementation

I think that the hashing should be a property method of the `NimbleConfiguration` class. The way I see it working is that the server or any other generation script can generate a configuration object as:

```
from nimble_orchestration.configuration import NimbleConfiguration
config = NimbleConfiguration(['NUC10i5FNH', 'Raspberry_Pi_4B'], parameters={"rack_height":21})
hash = config.hash
```

From here the server/script can check the build directory if a zip is available with a matching hash. If not it can use `OrchestrationRunner` to create everything that is needed and zip it up.

jmwright, 2024-05-15:
I think this is probably baked-in to the hashing methods you have mentioned, but it would be good to preserve the relationship between a configuration and a hash. That way we can do a naive sort of caching where if a configuration has already been generated and the server has not been rebooted (wiping out the temp files), we just send that zip to the user rather than burning the compute time to regenerate it.

My memory is that the rack height is calculated dynamically based on the number of shelves and the total height of those shelves combined. How will that work if you pass the `rack_height` as a parameter?

julianstirling, 2024-05-15:
> we just send that zip to the user rather than burning the compute time to regenerate it.

100%. Also more than that I think we need to *hash* or otherwise identify each shelf/rack component. As if you want a rack with 8 shelves and a height of 21. And we have already generated 7 of those shelves previously and a rack of the same size, then we should be copying over the rack components, and the 7 shelves from the cache and just generating 1 new shelf.

> How will that work if you pass the rack_height as a parameter?

Not yet implemented but my thought is that there are fixed sizes of peli-cases. So if you have 3 shelves and a tiny rack it will wobble around in the peli case and get damaged. So you probably want to be able to pick your rack size.

If your shelves need a larger rack you get an error. If you rack is bigger than your number of shelves you are told to print some blanking plates to cover the excess space.

Probably if you don't choose a rack size explicitly then it will default to a custom height rack as it currently does.

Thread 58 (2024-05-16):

Further standardise nimble parameters

julianstirling, 2024-05-16:
The parameters in `nimble_builder` are either hard coded or repeatedly specified in different files. Now we have a RackParameters class we should be using this to define hole sizes.

We need to
* [  ] Check through the code and find multiply defined parameters
* [  ] Change the rack legs so that they are specified by height in units not in length
* [  ] Make sure that screws go through clearance holes and then into tapped holes
* [  ] Decide on some standard rack parameters and think of how to pass specify them via cq-cli parameters

jmwright, 2024-05-17:
This might be scope creep for this PR, but we need to fix all the errant references to `tray` throughout the codebase. I think the "tray" naming convention came from me during the hackathon, but Wakoma uses the term "shelf", so we should fix the codebase to use that term. An example can be found [here](https://github.com/Wakoma/nimble/blob/master/mechanical/components/cadquery/tray_6in.py).

julianstirling, 2024-05-19:
This issue is things that I want to do after PR #57 is merged. 57 is already huge, but I wanted a list of things to do afterwards so they were not forgotten.

I 100% agree that is it a shelf or a tray is a key question and we need to standardise. Will make new issue rather than scope creep this one

drayde, 2024-06-10:
Concerning the task "_Stop using groups of strings for parameters and string comparisons, and start using enums_"

I'm actually a fan of parameter definitions like
` front_type: Literal["full", "open", "w-pattern", "slots"]`

My reasons:
- Very concise definition, no need to define an extra class
- Still a fully defined type
- So type use can be automatically checked
- Works with linters, and auto-completion in IDEs

If needed the types can also be named e.g.
`AxisType = Literal["X", "Y", "Z"]`

While there are still arguments to use enums in certain conditions, I would not vote for a general rule to ONLY use enums.

julianstirling, 2024-06-12:
Thanks @drayde, I suppose I am somewhat biased by a combination of my terrible spelling and the tools that I use that don't autocomplete this well. I have done a bit more learning and I can see there is more to this that meets the eye.

In terms of linting, typed inputs. This is something I don't get from PyLint. I assume we need a type checker like MyPy?

I think that the thing I like least about them is not when you are making a call to a function with a Literal input, but when you are writing the function itself. For the function itself there is no type checking when you actually do the string comparison to use the parameters. A spelling error here would be a really hard bug to detect or lint. Which I suppose is an argument for unit tests.

I can see this comes down to personal preference.

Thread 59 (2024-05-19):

Is it a tray or a shelf!?

julianstirling, 2024-05-19:
... we need to fix all the errant references to `tray` throughout the codebase. I think the "tray" naming convention came from me during the hackathon, but Wakoma uses the term "shelf", so we should fix the codebase to use that term. An example can be found [here](https://github.com/Wakoma/nimble/blob/master/mechanical/components/cadquery/tray_6in.py).

_Originally posted by @jmwright in https://github.com/Wakoma/nimble/issues/58#issuecomment-2117765846_
    
---

The code base uses both tray and shelf. Tray in the codebase also appears to have two meanings. Some times it means the whole shelf. Sometimes the shelf is divided up into the "front plate" and the "tray". Where the front plate is both the actual front plate and also any of the base that sits between the legs, whereas the tray is everything that sits entirely behind the legs (except in some cases when certain code switches are off.. which adds to confusion).

I think we need to:
* [ ] Do some naming standardisation in the existing repo
* [ ] Make a little diagram to explain the naming
* [ ] Enforce naming when doing code review

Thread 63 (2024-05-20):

License followup

julianstirling, 2024-05-20:
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

_Originally posted by @jmwright in https://github.com/Wakoma/nimble/issues/62#issuecomment-2120477345_

julianstirling, 2024-05-20:
I agree people are passionate. Unfortunately, I am one of them, but passionate for removing complications!

I also feel strongly that hardware should be covered by hardware licenses and that assembly instructions for hardware are part of the description of the hardware. They really _really_ should be under the same license, as they are essential to the hardware and inseparable from it, just like a doc-string is inseparable from a its Python function and therefore has the same license.

The issue we were fixing in PR #62  was having hardware creating code licensed under the AGPL which stops us licensing the hardware under CERN-OHL.

I 100% agree that actual software needs to be under a software license. I normally handle this by separating into two repositories. For example: [OpenFlexure Microscope Hardware](https://gitlab.com/openflexure/openflexure-microscope/) and [OpenFlexure Microscope Software](https://gitlab.com/openflexure/openflexure-microscope-server).
I worry about relying on headers, I am happy with a license file per folder or a clear explanation of what is under what license. But I prefer repository separation.

Nimble has no software, but we will be making a web-interface and server code. I can see that these really do want to be under a different license. Probably possibly AGPL.

I would personally suggest we make a repo called "Nimble Configuration Server" (or something similar) and move the server into that repo. That repo could always sub-module the main nimble repo to make it easier to develop. Or we can check it out in CI?

@jmwright would you be happy with this? What license should the server use?

jmwright, 2024-05-20:
> Nimble has no software, but we will be making a web-interface and server code.

I would argue that utilities like [this](https://github.com/Wakoma/nimble/blob/master/nimble_orchestration/devices_json_updater.py) count as software.

Also, CadQuery scripts (like OpenSCAD) fall into a weird category where they are both software and hardware source files. CadQuery files are good at capturing design intent when used properly, and essentially contain the necessary information to build a thing (can generate manufacturing/assembly drawings), but are still programming source code at their core.

> I would personally suggest we make a repo called "Nimble Configuration Server" (or something similar) and move the server into that repo.

Making it a separate repo sounds fine to me. I don't have a preference on the server license (AGPL vs something similar).

I don't know that we will agree on the single-license-file-to-rule-them-all argument, but I don't want to get us bogged down either. Licensing is a kind of holy war that I do not have the spare energy for. We need to keep moving, and I feel like we are in a "good enough" position for now, but I do think it is good to leave space for discussion and change (if needed) in the future.

julianstirling, 2024-05-20:
I agree that holy-wars are not what we want.
Code CAD does occupy an interesting space where it is both softwarey and hardwarey. I think my point would always be as that if the result from the code is something that will be physically made. Then you should use a hardware license as it covers what happens to that physical object. The CERN OHL defines this as:

> 'Complete Source' means the set of all Source necessary to Make
      a Product, in the preferred form for making modifications,
      including necessary installation and interfacing information
      both for the Product, and for any included Available Components.
      If the format is proprietary, it must also be made available in
      a format (if the proprietary tool can create it) which is
      viewable with a tool available to potential licensees and
      licensed under a licence approved by the Free Software
      Foundation or the Open Source Initiative. Complete Source need
      not include the Source of any Available Component, provided that
      You include in the Complete Source sufficient information to
      enable a recipient to Make or source and use the Available
      Component to Make the Product.

I think CadQuery and OpenSCAD fit well into this.

You make a good point that `devices_json_updater.py` is different and may want a different license.

My gut feeling is that the complexity of licensing within a repo is 2^(n), where n is the number of extra licenses. If we really do need extra licenses, that is OK. But they should be added with caution, and carefully discussed so everyone is happy, hopefully thus avoiding a Holy War.

julianstirling, 2024-06-21:
I am closing this as now that the bulk of the orchestration and the server is separated from the CAD the licensing is more clear. There are still some project specific stand-alone utilities may want their own license at some point. As these stand alone and are quite simple they are probably best under permissive licenses to minimise license complexity.

Closed 2024-07-01.

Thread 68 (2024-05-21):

Information for shelf types in `tray_6in.py` needs to be available to other functions

julianstirling, 2024-05-21:
Currently the information for how each individual shelf is built is held ad-hoc in a set of functions in `tray_6in.py`. Some of this information is needed for other parts of the orchestration.

For example if the shelves are broad they need to be a added into the rack before the top is put on. Therefore the instructions need to be different.

We will need some way of holding the information for the shelves in a way that it can be polled without having to run the script the builds the shelf.

drayde, 2024-05-21:
Is there more than the broad type information that would need to be available?
One way to tackle this would be to structure the assembly instructions so that all types are assembled the same way (start at the bottom, work up to the top most shelf, than add the top.

If we really need that info outside of the build functions, I would like to do the code refactoring

julianstirling, 2024-05-22:
> Is there more than the broad type information that would need to be available? One way to tackle this would be to structure the assembly instructions so that all types are assembled the same way (start at the bottom, work up to the top most shelf, than add the top.
>
> If we really need that info outside of the build functions, I would like to do the code refactoring

Either way we will need the information available because they will slide over the legs rather than slide into the front. We need this sort of information so we can do exploded renders and renders of each assembly step happening.

The code must be written from the perspective that the final goal is to have step by step rendered instructions
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
This is simply not possible if parameters are hard coded into the the functions that CadQuery process.

We have done significant refactoring already to try to centralise parameters and there is still a huge amount to be done before we can get the CAD side of this project back on track. Any refactoring must be done with a proper understanding of what information is needed where, and probably won't happen until I have done a significant amount more parameter centralising.

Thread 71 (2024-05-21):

Fastener Models in Assemblies

jmwright, 2024-05-21:
We have started to discuss adding fasteners to assemblies, specifically metric screws to install components into shelves, and screws to mount the shelves into the rack. It looks like there is only one complete generator library at this time, and that is [cq_warehouse](https://cq-warehouse.readthedocs.io/en/latest/fastener.html). It does other things besides fasteners, but I doubt we need any of the other parts it generates.

The alternative is to generate our own fasteners, but there is a surprising amount of nuance in fasteners that can make them tedious to create.

julianstirling, 2024-05-22:
My vote is to use cq_warehouse. Better to use a package than reinvent the wheel.

jmwright, 2024-05-30:
The cq_warehouse dependency has been added in draft PR #75

jmwright, 2024-10-21:
The assemblies that have been done so far have fasteners. Screws are created using cq_warehouse, and I created zip tie fasteners as well.

Closed 2024-10-21.

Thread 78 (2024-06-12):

Plan data structure and information flow

julianstirling, 2024-06-12:
We need to make sure that the correct data is available to each step of generating the hardware and instructions. A first approximation is that the following data is needed for the three main steps:

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

I think the easiest way to do this is some sort of heptarchical object-based structure. Very simplistically this will look somewhat like:

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

This way the orchestration can:

1. Receive list of networking hardware and rack parameters
2. Pass parameters into full assembly object
    1. Orchestration adds networking component to object
    2. Assembly object then creates shelf object based on this (needs access to database to know what shelf type and other information.)
3. Get ExSource from assembly object to get full list of parts and renders that need to be generated (object will need to query the other objects it contains)
4. Run ExSource
5. Get textual instructions from assembly object (object will need to query the other objects it contains)
6. Run GitBuilding

## Shelf classes

- We will need a base high level shelf class that contains all the basic structure.
- We will then need a generic shelf class that creates the shelf (and stores other info) for any networking hardware that doesn't have specific shelves
- We will need child classes for the very specific shelves for certain components.

jmwright, 2024-06-14:
I don't think anything in the data flow precludes this, but it will probably be easier to make the shelves into sub-assemblies along with their components, screws, etc, and then have the entire rack be built of shelf-component sub-assemblies along with the odd bits that are left over (top and bottom plates, rails, screws to fasten sub-assemblies to rails, etc). This could imply a matching hierarchy in the data.

julianstirling, 2024-06-21:
I'm closing this as we have have a plan. I'm sure the plan will be updated as we find the issues.

Closed 2024-06-21.

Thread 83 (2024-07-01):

Export file types and efficency

julianstirling, 2024-07-01:
Currently we export multiple file types from CadQuery using ExSource. I think we currently build each from scratch which isn't efficient.

Some thoughts

- Can cqcli/exsource be modified to allow multiple file types to be exported without rebuilding the shape
- Can we import STLs into CadQuery if we are assembling them?

in #79 there @jmwright mentions"

> I believe there is a plugin that allows STLs to be imported, but STL->STEP conversion can get pretty messy if it is a complex shape with non-planar faces.

I STL import is something to look into. The messyness STL->STEP conversion depends on the implementation. STEP itself is happy to hold mesh information. So as long as there is no attempt to change the underlying shape to B-rep then nothing should break. For our case as we are only doing assembly rather than modification of the shape there is no reason we need to be modifying the STLs, so conversion to B-rep shouldn't be needed. It is worth checking whether the plug in always tries to do B-rep conversion.

If it doesn't this will allow STLs made in other programs like OpenSCAD to be assembled with CadQuery, which would be nice.

jmwright, 2024-07-01:
The STL importer I was referencing is [here](https://github.com/JustinSDK/cqMore/blob/main/examples/import_stl.py), and is part of the cqMore library. I used it to convert a 3D scan of a camera trap from STL to STEP in CadQuery. The result is [here](https://codeberg.org/7BIndustries/poc-stereoscope/src/branch/main/stereoscope/components/cameras/camera_trap_simplified_10k.step). I had to clean up and simplify the mesh in MeshLab before CadQuery could handle it.

julianstirling, 2024-07-01:
Right, that super useful. I can imagine a 3D scan having a much more complex mesh than our shelves. We can also use [admesh](https://pypi.org/project/admesh/) to check for and clean mesh issues if we need to.

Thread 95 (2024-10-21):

shelf_id Bug

jmwright, 2024-10-21:
The code [here](https://github.com/Wakoma/nimble/blob/master/nimble_build_system/orchestration/device.py#L117) in device.py that gets the `shelf_builder_id` is supposed to just strip a trailing `-6` or `-st`, but it seems to incorrectly force some shelf IDs to be `generic`.

The following JSON in devices.json leads to a generic shelf.
```
{"ID": "Western_Digital_Red_HDD","Type": "Storage","Hardware": "Western Digital Red HDD","Brand": "Western Digital", "Model": "WD20EFAX","Shelf": "HDD 3.5 Shelf","Rack": "6 in","ShelfId": "hdd35","HeightUnits": "2","LengthMm": "147.07 mm","Depth": "101.60 mm","Height": "26.16 mm","PoEIn": "","PoEOut": "","WattageMax": "","EstCostUsd": "$131.00","ProductWebsiteUsd": "","ProductWebsiteEur": "https://www.amazon.de/-/en/Western-Digital-Internal-Hard-Drive/dp/B083XVY99B/ref=sr_1_5","RAM": "","Field19": "","PoEInInputVoltage": "","Voltage": "","Amperage": "","WRTVersion": "","OpenWRTLink": "","Comments": "Part number is for the 2TB version"}
```

Whereas adding a `-6` to the `ShelfId` fixes the issue.
```
{"ID": "Western_Digital_Red_HDD","Type": "Storage","Hardware": "Western Digital Red HDD","Brand": "Western Digital", "Model": "WD20EFAX","Shelf": "HDD 3.5 Shelf","Rack": "6 in","ShelfId": "hdd35-6","HeightUnits": "2","LengthMm": "147.07 mm","Depth": "101.60 mm","Height": "26.16 mm","PoEIn": "","PoEOut": "","WattageMax": "","EstCostUsd": "$131.00","ProductWebsiteUsd": "","ProductWebsiteEur": "https://www.amazon.de/-/en/Western-Digital-Internal-Hard-Drive/dp/B083XVY99B/ref=sr_1_5","RAM": "","Field19": "","PoEInInputVoltage": "","Voltage": "","Amperage": "","WRTVersion": "","OpenWRTLink": "","Comments": "Part number is for the 2TB version"}
```

@julianstirling

julianstirling, 2024-10-21:
This is legacy code. Currently the way it works is that it has to match the regex, which involves the -6 but then the -6 is stripped off.

I think having the shelf_id in the database itself is the problem. Because it splits the thinking, and means we have to update both the database and the cad to update how we build for a shelf.

The database should tell us what the hardware is. If we have made a shelf that can accept that hardware the the CAD side should know this. As we have said before we really need to have a think about what data actually belongs in the database.

jmwright, 2024-10-21:
@julianstirling So for now since I am trying to get the assemblies working, should I just add the `-6`?

julianstirling, 2024-10-21:
Yeah I think that's best

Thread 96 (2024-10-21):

Multiple Devices in One Shelf

jmwright, 2024-10-21:
We have code for a shelf that seems to be designed to hold 2x 2.5" SSD drives [code here](https://github.com/Wakoma/nimble/blob/master/nimble_build_system/cad/shelf.py#L702). I do not see anywhere to define that multiple devices should fit into one shelf. We would need information like spacing between devices. For now I am just going to create a single placeholder device that takes up the space of two 2.5" SSDs, but it's not a proper solution.

julianstirling, 2024-10-21:
I think this is where the reading from the database fails, we shouldn't try to add every single specific hard drive into out dropdowns as there is no good reason for this.

I think what we should show is something like:

Storage:
* One 3.5" HDD
* One 2.5" SDD
* Two 2.5" SDDs

The last two should probably be the same physical shelf, but we do instructions for only one.

---

FYI. I wouldn't do anything too complex for all the other shelves until we check that it works end to end with CadOrchestrator. I have just added the "add render" option to CadOrchestraor, it is ready for review. Once that is added we can update the nimble code to use this and to generate end to end (even if its a bit slowly via ExSoruce).

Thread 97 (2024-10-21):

HDD 3.5" Mounting Hole Spacing

jmwright, 2024-10-21:
@ericnitschke Have you printed one of the HDD 3.5" shelves to do a test fit? It looks like the hole spacing may be wrong on the shelf based on [this document](https://support.wdc.com/images/kb/2579-771970-A03.pdf) from Western Digital.

ericnitschke, 2024-10-21:
Just the old/original version of the shelf, which works fine. It only uses two screws but holds the drive well. Pics [1](https://wakoma.co/wp-content/uploads/2024/10/hdd2-scaled.jpeg) [2](https://wakoma.co/wp-content/uploads/2024/10/hdd1-scaled.jpeg) I don't think we have a parametric design for this one.

jmwright, 2024-10-21:
Thanks @ericnitschke

Closed 2024-10-21.

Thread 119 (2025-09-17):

Implement devices with 10 in Rack

kny5, 2025-09-17:
This devices were ruled out due to rendering inconsistencies.

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

An "if statement at "gen_nimble_conf_options.py" is set to filter out all but "6in" devices.

Requirements for enabling devices:
check the 10 in tray design and rendering rules.
check the data COMPLETION at the single source of truth, nocodb,
check the data dimensions ACCURACY.

Please comment and increase the requirements list.

jmwright, 2025-09-17:
I am not certain, but I think 10 inch rack designs are left for a future project. @ericnitschke will probably know for sure.

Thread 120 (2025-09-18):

End Plate Mounting Screws in BOM Do Not Match Code and CAD

jmwright, 2025-09-18:
The screws for the top and base plates in the code/CAD are specified as M5-0.8 and look to be the correct size in the renders, but the generated BOM shows the screws as M4 instead (the counter sunk ones in the screenshot below).

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

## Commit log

2021-03-18 Add design for top
    [top-draft-v2.1-3mm.stl]
2021-03-18 Move file
    [top-draft-v2.1-3mm.stl]
2021-04-23 Add files via upload
    New 3D designs
    [Wakoma Nimble - AP Mount for 1430 - New v1.5 Bottom.stl, Wakoma Nimble - AP Mount for 1430 - New v1.5 Top.stl, Wakoma Nimble - Bottom v2.1-3mm.stl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]
2023-01-26 Add some freecad designs
    [case-top-draft.FCStd, patch-panel.FCStd]
2023-02-26 New Shelves Added
    [Wakoma Nimble - Flex Mini Shelf v1.4.stl, Wakoma Nimble - Keystone Patch Panel 2 Units Short- v1.2.stl, Wakoma Nimble - LtAP mini Shallow v1.0.stl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]
2023-03-06 Moves files into the osh-dir-std structure
    [Wakoma Nimble - 3.5 HDD Shelf v1.0.stl, Wakoma Nimble - AP Mount for 1430 - New v1.5 Bottom.stl, Wakoma Nimble - AP Mount for 1430 - New v1.5 Top.stl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]
2023-03-06 Cleans-up file names
    [Wakoma_Nimble_-_3.5_HDD_Shelf_v1.0.stl, Wakoma_Nimble_-_AP_Mount_for_1430_-_New_v1.5.stl, Wakoma_Nimble_-_AP_Mount_for_1430_-_New_v1.5_Bottom.stl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]
2023-03-06 Adds NextCloud content from "3D Designs"
    [Wakoma_NUC_Shelf_1.3.stl, Wakoma_Nimble_-_Tall_NUC_Shelf_v1.2.stl, Wakoma_Power_Box_v1.3.stl]
2023-03-06 Fixes dir for wiring diagram (electronics, not mechanics)
2023-03-06 Rename stl files
    [wakoma_nimble_3.5_hdd_shelf.stl, wakoma_nimble_ap_mount_for_1430.stl, wakoma_nimble_ap_mount_for_1430_bottom.stl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]
2023-03-06 *Rename stl files
    - Remove redundant wakoma_nimble prefix
    [3.5_hdd_shelf.stl, ap_mount_for_1430.stl, ap_mount_for_1430_bottom.stl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]
2023-03-06 *Rename stl files
    - remove redundant prefix
    [nuc_shelf.stl, nuc_shelf2.stl, nuc_shelf_tall.stl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]
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2023-03-06 Removes a version number from the wiring diagram source file name
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2023-03-06 Add a template for osh-autodoc/cadquery
    [1-align-the-base-parts.csv, 2-attach-the-block-parts.csv, 3-attach-the-fixed-jaw-parts.csv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]
2023-03-06 base parametric FreeCAD model for generic shelf
    [base_shelf.FCStd]
2023-03-06 Start porting omni_20_top
    [omni_20_top.FCStd]
2023-03-06 added quick and dirty side reliefs (triangles)
    [base_shelf.FCStd]
2023-03-06 moved kicad base_shelf to src/
    [base_shelf.FCStd]
2023-03-06 Updates STL file priority for the legs to 10
2023-03-06 Fix email typo in license files
    [omni_20_top.FCStd]
2023-03-06 Add triangle pattern
    for the triangle pattern
    [Triangle master.FCStd]
2023-03-06 Adds *.obj exports of ThinkerCAD models
    [tinker.obj]
2023-03-06 Clean-up dimensions
    [Triangle master.FCStd, triangle_master.FCStd]
2023-03-06 renamed body and features
    [base_shelf.FCStd]
2023-03-06 Raspberry Pi 4B shelf
    [rpi_4b_shelf.FCStd]
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2023-03-06 Pad basic design
    - need to parametrize dimensions
    [omni_20_top.FCStd]
2023-03-06 Update design
    [omni_20_top.FCStd]
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2023-03-07 fixed assembly
2023-03-07 Add rails
    [master_rail.FCStd]
2023-03-07 Add zip ties to the base shelf
    [base_shelf.FCStd]
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2023-03-07 Add hole mesh
    [base_shelf.FCStd]
2023-03-10 Add parametrisation of zip and hole mesh
    [base_shelf.FCStd]
2023-10-10 1st draft for new structure
    [1-align-the-base-parts.csv, 2-attach-the-block-parts.csv, 3-attach-the-fixed-jaw-parts.csv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]
2023-12-13 Very basic working back end with sample front end and rack leg model
2024-01-04 Updated the rack leg model and the server for the first release of CadScript
2024-01-05 get current cadscript dev branch instead of released version
2024-01-05 Fixed wrong function name in rack leg code
2024-01-08 Updated rack leg to make hole spacing correctly dynamic
2024-01-16 Naive implementation of having the sample web front end download a completed build from the backend
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2024-02-26 publish STL files on a temporary static web site as a github action
2024-05-09 Reorganise repository structure
    [1-align-the-base-parts.csv, 2-attach-the-block-parts.csv, 3-attach-the-fixed-jaw-parts.csv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]
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2024-05-15 First pass at updating devices.json with associated fixes
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2024-05-15 Add pylintrc file for cad-query scripts, stop disabling error on show_object in each script
2024-05-15 Fix linting errors and tidy the devices updater
2024-05-19 Fix assembly configuration so shelfbuilder shelves assemble in correct location
2024-05-20 Remove freecad-stl-script as AGPL licensed and this is now handled by ExSource
2024-05-20 glTF fixes and colours
    Assembly now uses a binary glTF (.glb) due to upstream bug
    with ACSII glTF. Adding colours to the glTF assembly so different
    components can be recognised.
2024-05-21 Configuration to better track shelves via Shelf object
2024-05-21 Add gitbuilding page for each shelf to main docs, add assembly glb to docs
2024-05-22 Added a button to view the generated docs
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2024-06-20 Changing the devices.json license to Wakoma as this is now pulled from their NocoDb
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2024-07-08 Move Legacy CAD files into mechanical directory
    [3.5_hdd_shelf.stl, ap_mount_for_1430.stl, ap_mount_for_1430_bottom.stl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]
2024-08-13 Trying to get back to where the CAD Lint is passing
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2024-08-15 Adjusting AssembledComponent data into new more flexible format
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2024-08-19 Added create_shelf_for function that handles shelf object creation and Device object creation
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2024-08-20 Reworked test to start identifying broken device/shelf combos
2024-08-21 Fixed the bug with the shelf CAD returning a CadQuery object
2024-08-22 Added CAD model build efficiency and started trying to diagnose test failure in CI
2024-08-24 Started adding assembly parameters and a test for colliding parts in the shelf-device assembly
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2024-09-18 Trying to pin the cadquery-ocp version to prevent segfault
2024-09-18 Switching back to ubuntu-latest as the problem may be in the VTK options in the plugin
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2024-09-24 Fixes for RPi shelf assembly
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2024-09-26 Trying suggested GitBuilding version pin to fix CI
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2024-10-24 Added unifi flex mini shelf assembly
2024-10-24 Added Unifi Switch Flex shelf assembly
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2024-10-24 Fixed screw size and length for Unifi Flex Switch
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2024-11-06 I got overzealous and removed the line of code that generated the shelf assembly for the rack, so I put it back
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2024-12-19 Shelf assembly moved to out of __init__, renders in docs
    Shelf assmebly moved out of direct coding in __init__ so that other
    code could reliably be run before and after when super() was called
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2025-01-09 Fixed failing tests now that CQ Assemblies are breaking deepcopy
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2025-01-20 Set whether shelf is broad when shelf class is created so this data is available for rack assembly docs
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2025-02-19 Modified: gen_nimble_conf_options.py, added if statement filtering all but 6 in, rack sizes, preventing oversized models in rendering.
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2025-09-02 mod devices.json NOTE: control of parsing must be keep on the updating code, not in NOCODB.
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2025-09-04 Fixed Dockerfile bugged RUN updater and generator for devices.
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2025-09-07 Testing flipped Y axis value
2025-09-07 Discarded bug by get_offset function for NUC devices.
2025-09-09 Loosening requirements.txt for build/test --cut
2025-09-09 Loosening requirements.txt for build/test --cut-1
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2025-09-25 Fixed an assembly bounding box calculation that was causing mounting screws to be out of position
2025-09-25 Tweaked ziptie sizing and handle ziptie devices that are too wide but their depth is ok
2025-09-26 Made Raspberry Pi 5 masquerade as a Pi 4B since their hole patterns match up.
2025-09-26 Fixed Gateway Lite device which looks the same and is the same size as the UniFi Express
2025-10-02 Fixed M4 being specified instead of M5 for attaching end caps
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

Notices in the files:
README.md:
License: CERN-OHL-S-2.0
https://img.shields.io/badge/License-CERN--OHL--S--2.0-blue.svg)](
